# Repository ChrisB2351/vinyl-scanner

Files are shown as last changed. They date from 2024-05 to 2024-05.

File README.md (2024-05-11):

# Vinyl Scanner

The vinyl scanner is a project we started with the idea of tracking our vinyl collection, as well as tracking the times we play our albums. Think of Last.fm, but handmade and self-hosted. We have it hanging above the record player.

It is composed by two parts: a wooden shelf with an ESP32 device, and a server program that runs somewhere else. The shelf holds the vinyl while we're playing it, and the ESP32 inside contacts the server to track the vinyl we're playing. Therefore, each vinyl must have its own NFC tag in order to be trackable.

## Clone

This repository contains Git submodules. Therefore, when cloning it, don't
forget to clone it with submodules:

```shell
git clone --recurse-submodules https://github.com/ChrisB2351/vinyl-scanner
```

## Shelf

The shelf was made out of 3mm multiplex wood and the "Playing Now" sign out of acrylic. The schematics for laser cutting can be found in the following files:

- [`docs/shelf.pdf`](./docs/shelf.pdf): ready to print PDF file exported to life-size.
- [`docs/shelf.dwg`](./docs/shelf.dwg): original file with the schematics and a layer with the dimensions. 

After laser cutting, we would advise to put some light blocking foam on the inside, so that the light does not shine through the thin multiplex. Additionally, some extra holes have to be drilled in the bottom plate and the backplate to make space for the nuts and bolts to keep it all together.

## Documentation

You can find more documentation in the following files:

- [`arduino`](./arduino/README.md) includes more information regarding the ESP32 module.
- [`server`](./server/README.md) includes more information regarding the server software.

## License

[MIT License](./LICENSE)

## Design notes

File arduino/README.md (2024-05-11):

# Arduino / ESP32 Module

The [Vinyl Player](../) ESP32 is the hardware that is embedded inside the wooden shelf. It is responsible for detecting the vinyl NFC tags and communicating with the server about the newly read vinyls.

## Schematics



The ESP32 (on the left) communicates with the sensor (on the right) using RX-TX communication. On the ESP32 the pins RX2 and TX2 are connected to TX and RX pins of the sensor.

The LED strip is connected to datapin 15 (can be another digital pin if defined in the code).

## Build & Run

We use [platform.io](https://platformio.org/) with VSCode to deploy our code to the ESP32.

## Configuration

You need to copy the file [`include/secrets.example.h`](./include/secrets.example.h) to `include/secrets.h` and fill it with the correct Wi-Fi credentials, as well as the URL of the server endpoint.

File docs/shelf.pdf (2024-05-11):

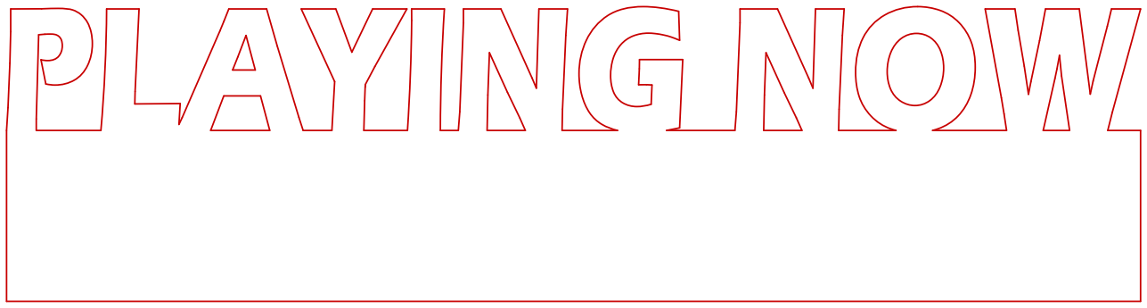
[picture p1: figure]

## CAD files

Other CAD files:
docs/shelf.dwg

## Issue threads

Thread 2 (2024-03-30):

Readme and docs

hacdias, 2024-03-30:
- [ ] Write readme
- [ ] Laser cutting document
- [ ] Photos
- [ ] How to run the server
- [ ] How to run the arduino
- [ ] Arduino schematics

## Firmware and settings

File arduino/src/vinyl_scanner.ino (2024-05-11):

#include <PN532.h>
#include <PN532_HSU.h>
#include <Adafruit_NeoPixel.h>
#include <WiFi.h>
#include <WiFiClientSecure.h>
#include <HTTPClient.h>
#include <secrets.h>

#define TIMEZONE_OFFSET 1 * 3600
#define LED_BUILTIN     2
#define PIN_WS2812B 15  // The ESP32 pin GPIO15 connected to WS2812B
#define NUM_PIXELS 30   // The number of LEDs (pixels) on WS2812B LED strip

Adafruit_NeoPixel ws2812b(NUM_PIXELS, PIN_WS2812B, NEO_GRB + NEO_KHZ800);
unsigned long pixelsInterval=10;  // time to wait
unsigned long rainbowPreviousMillis=0;
unsigned long rainbowCyclesPreviousMillis=0;
int rainbowCycleCycles = 0;
uint16_t currentPixel = 0;// what pixel are we operating on

WiFiClientSecure client;
PN532_HSU pn532hsu(Serial2);
PN532 nfc(pn532hsu);

uint64_t timestamp_millis;
String prev_uid;
bool vinyl_present = false;
bool lights_on = false;

void setup() {
  Serial.begin(115200);
  delay(100);

  nfc.begin();
  // Setup PN53x / NFC module
  uint32_t nfcVersion = nfc.getFirmwareVersion();
  if (! nfcVersion) {
    Serial.print("PN53x not found");
    while (1); // block forever
  }
  Serial.print("Found chip PN5"); Serial.println((nfcVersion >> 24) & 0xFF, HEX);
  Serial.print("Firmware ver. "); Serial.print((nfcVersion >> 16) & 0xFF, DEC);
  Serial.print('.'); Serial.println((nfcVersion >> 8) & 0xFF, DEC);
  nfc.SAMConfig();
  Serial.println("NFC module initialized");

  // Setup Wi-Fi
  WiFi.mode(WIFI_STA);
  WiFi.begin(WIFI_SSID, WIFI_PASSWORD);
  while (WiFi.status() != WL_CONNECTED) {
    delay(500);
    Serial.print(".");
  }
  Serial.println("");
  Serial.println("WiFi connected");

  // Initialize WS2812B strip object (REQUIRED)
  ws2812b.begin();
  timestamp_millis = millis();
}

void sendVinylId(String id) {
  HTTPClient http;
  http.begin(ENDPOINT);
  http.addHeader("Authorization", "Token " + String(ENDPOINT_TOKEN));

  int statusCode = http.POST(id);
  if (statusCode != 200) {
    Serial.printf("HTTP GET to %s failed with status code: %d\n", ENDPOINT, statusCode);
  }
  http.end();
}

String formatUid(uint8_t length, uint8_t uid[]) {
  String str;
  for (byte i = 0; i < length; i++) {
    // Convert each byte to a hexadecimal string representation
    String byteString = String(uid[i], HEX);
    // If the byte is less than 0x10, add a leading zero for consistency
    if (uid[i] < 0x10) {
      byteString = "0" + byteString;
    }
    // Concatenate the byte string to the UID string
    str += byteString;
  }
  return str;
}

// rainbow code from https://github.com/ndsh/neopixel-without-delay/tree/master?tab=readme-ov-file
void rainbow() {
  for(uint16_t i = 0; i< ws2812b.numPixels(); i++) {
      ws2812b.setPixelColor(i, Wheel(((i * 256 / ws2812b.numPixels()) + rainbowCycleCycles) & 255));
  }
  ws2812b.show();

  rainbowCycleCycles++;
  if(rainbowCycleCycles >= 256*5) rainbowCycleCycles = 0;
}

uint32_t Wheel(byte WheelPos) {
  WheelPos = 255 - WheelPos;
  if(WheelPos < 85) {
    return ws2812b.Color(255 - WheelPos * 3, 0, WheelPos * 3);
  }
  if(WheelPos < 170) {
    WheelPos -= 85;
    return ws2812b.Color(0, WheelPos * 3, 255 - WheelPos * 3);
  }
  WheelPos -= 170;
  return ws2812b.Color(WheelPos * 3, 255 - WheelPos * 3, 0);
}

void loop() {
  uint8_t success;
  uint8_t uid[] = { 0, 0, 0, 0, 0, 0, 0 };
  uint8_t uidLength;
  success = nfc.readPassiveTargetID(PN532_MIFARE_ISO14443A, uid, &uidLength); // Informações do NFC

  if (success) {
    vinyl_present = true;
    timestamp_millis = millis();
    String uidString = formatUid(uidLength, uid);

    if (prev_uid != uidString){
      Serial.printf("Found an ISO14443A card\n");
      Serial.printf("\tUID Length: %d bytes\n", uidLength);
      Serial.printf("\tUID Value: %s\n\n", uidString.c_str());
      Serial.printf("\tPrevious value: %s\n\n", prev_uid.c_str());

      sendVinylId(uidString);
      prev_uid = uidString;
    }
  }

  // If vinyl is present keep playing rainbow animation
  if (vinyl_present){
    if ((unsigned long)(millis() - rainbowPreviousMillis) >= pixelsInterval) {
      rainbowPreviousMillis = millis();
      rainbow();
    }
  }
  // If there is no tag scanned for 500 ms turn off the led strip and reset vinyl_present variable
  if (millis() - timestamp_millis > 500 && vinyl_present){
    vinyl_present = false;
    ws2812b.clear();  
    ws2812b.show();  
  }
}

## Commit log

2024-02-09 arduino: initial commit
2024-02-10 arduino: configure libraries
2024-03-18 arduino: add color label
2024-03-24 arduino: vendor working PN532 module
    The adafruit module did not work properly with our UART
    connection. Therefore, we are now vendoring a different
    module which unfortunately does not support dependency
    management.
    [vinyl_scanner.ino]
2024-03-30 new led animation, and handle tags being there for long periods of time
2024-05-11 docs: shelf schematics, readme updates
    [shelf.dwg]
2024-05-11 docs: arduino schematics
2024-05-15 server: better button contrast
